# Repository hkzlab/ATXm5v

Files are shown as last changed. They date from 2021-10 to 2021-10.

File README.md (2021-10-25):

# ATX -5V inline injector

## Introduction

I needed a quick and cheap way to get -5V available on a modern ATX PSU. The current requirements were risible, so I just made an inline module that takes -12V and regulates down to -5V using a simple and cheap 7905.

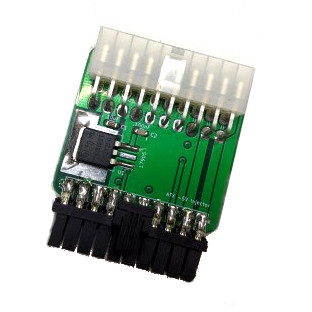
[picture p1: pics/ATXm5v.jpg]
Rev. 1.0 PCB


### Disclaimer

I take NO responsibility for what happens if you decide to build and use this device. Your computer might crash, catch fire or be destroyed in other nasty ways.

## Bill of Materials

| Component | Qty | Type / Value |
| --- | --- | --- |
| J1 |  1  | Molex 39-30-1200 |
| J2 |  1  | Molex 172708-0020 |
| Pins for J2 |  20 | Molex 172718-1111 |
| U1 |  1  | 7905 (TO-263) |
| C1 |  1  | 10uF/16v 1206 ceramic |
| C2 |  1  | 100nF 1206 ceramic |

### Notes

Cut away the excess plastic from the Molex 172708-0020, fit in all the pins, and then slide the PCB between them. Then solder them, making sure they don't touch.

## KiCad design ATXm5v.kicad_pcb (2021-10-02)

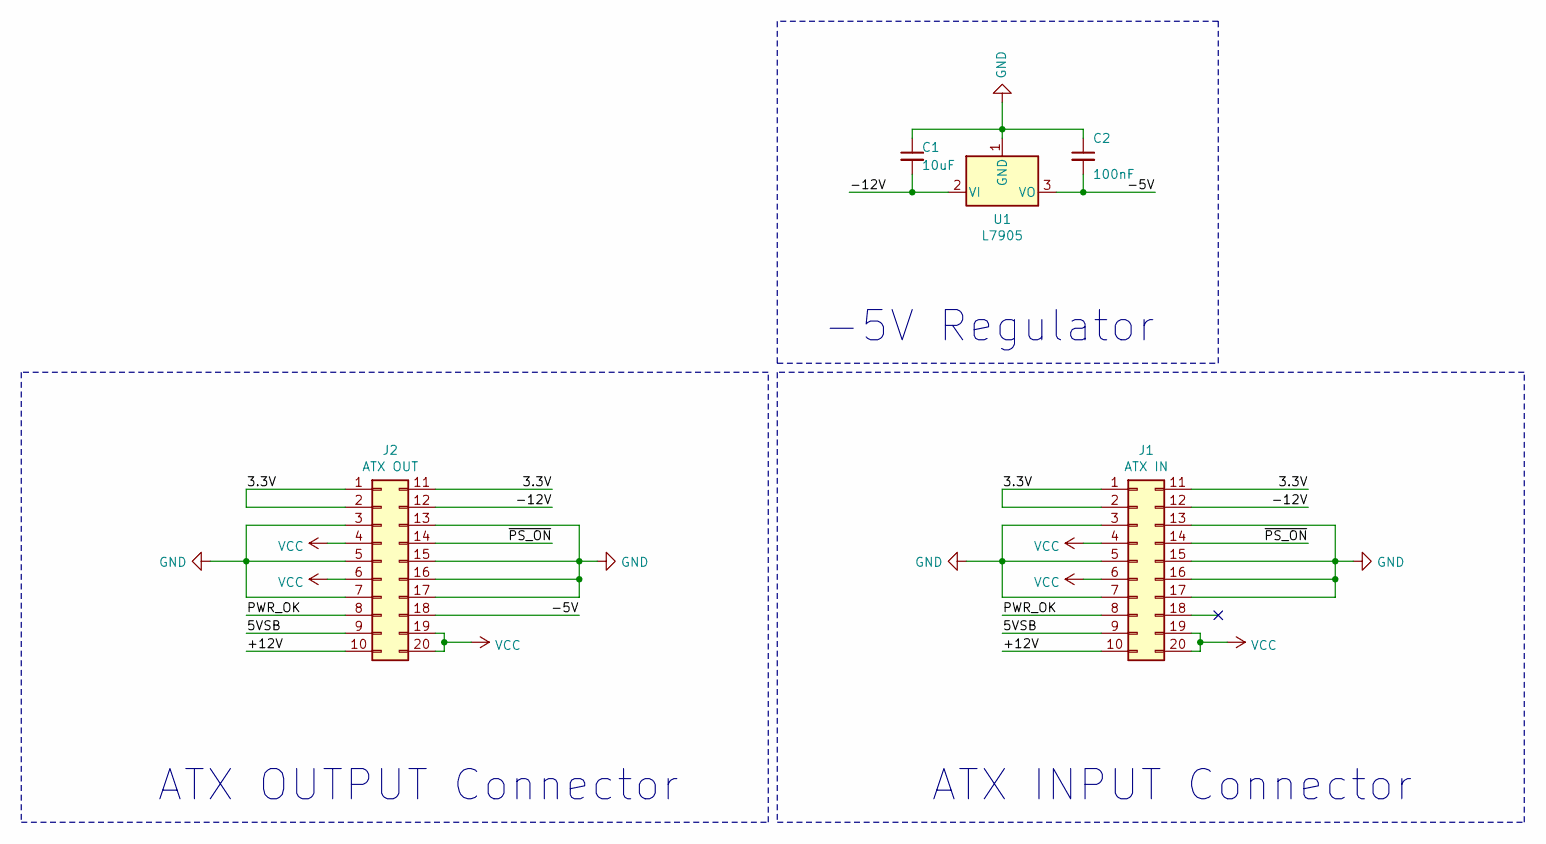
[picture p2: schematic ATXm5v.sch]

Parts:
C1: 10uF; C_1206_3216Metric_Pad1.33x1.80mm_HandSolder
C2: 100nF; C_1206_3216Metric_Pad1.33x1.80mm_HandSolder
J1: ATX IN; Molex_Mini-Fit_Jr_5569-20A2_2x10_P4.20mm_Horizontal
J2: ATX OUT; ATX-Edge
U1: L7905; TO-263-3_TabPin2

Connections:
/3.3V: J1.1, J1.2, J1.11, J2.1, J2.2, J2.11
/5VSB: J1.9, J2.9
/+12V: J1.10, J2.10
/-5V: C2.2, J2.18, U1.3 (VO)
/-12V: C1.2, J1.12, J2.12, U1.2 (VI)
/PWR_OK: J1.8, J2.8
/~PS_ON: J1.14, J2.14
GND: C1.1, C2.1, J1.3, J1.5, J1.7, J1.13, J1.15, J1.16, J1.17, J2.3, J2.5, J2.7, J2.13, J2.15, J2.16, J2.17, U1.1 (GND)
VCC: J1.4, J1.6, J1.19, J1.20, J2.4, J2.6, J2.19, J2.20

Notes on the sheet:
-5V Regulator
ATX INPUT Connector
ATX OUTPUT Connector

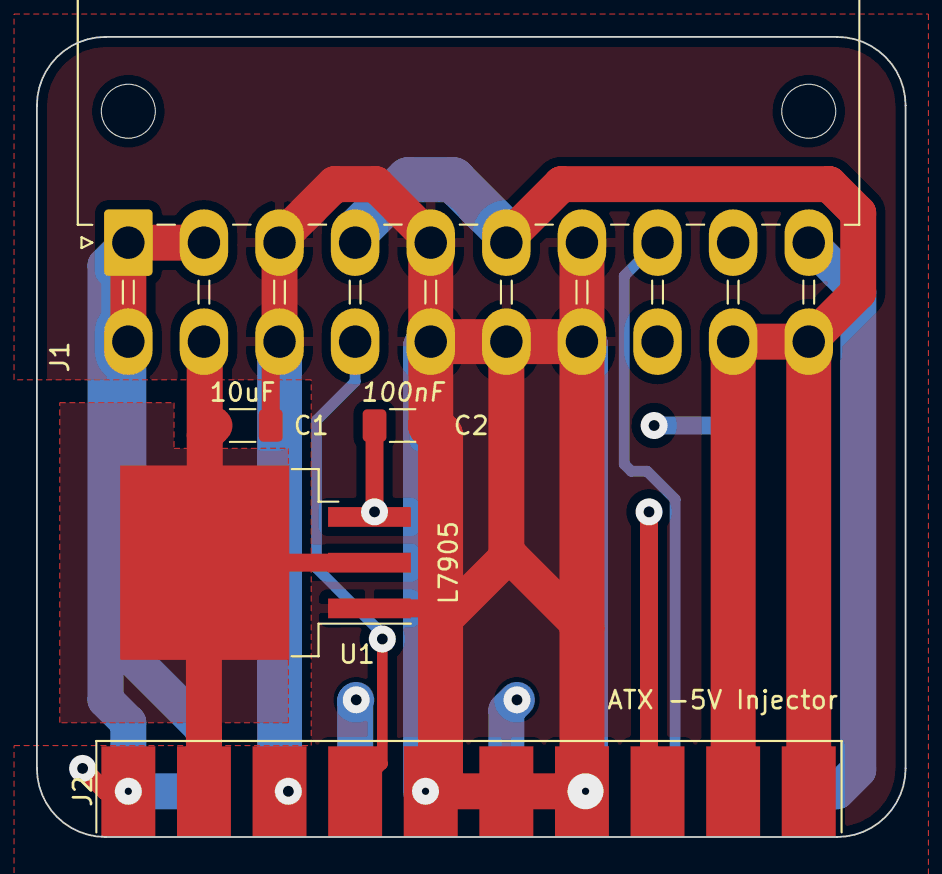
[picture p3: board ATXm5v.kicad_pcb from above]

Board: 4 copper layers, 48.3 x 44.5 mm, 5 parts (0 on the bottom side), 9 nets.

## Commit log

2021-09-25 Add initial pcb
    [ATXm5v.kicad_pcb, ATXm5v.sch]
2021-09-25 Add heatsink plane for regulator
    [ATXm5v.kicad_pcb]
2021-09-25 Add relief for linear reg
    [ATXm5v.kicad_pcb]
2021-09-25 First revision of the board
    [ATXm5v.kicad_pcb]
2021-09-29 basic gerbers
2021-09-29 Fix footprint
    [ATXm5v.kicad_pcb]
2021-10-02 Fixed connector direction
    [ATXm5v.kicad_pcb]
2021-11-09 Change KiCad URL
